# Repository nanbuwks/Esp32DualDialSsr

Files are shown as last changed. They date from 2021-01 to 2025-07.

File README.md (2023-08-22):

# Esp32DualDialSsr

ESP32 board with 2 rotary encoder and 4 ch SSR.

# OVERVIEW


include AC to 12V DC power module and AC (SSR driven 12V). 
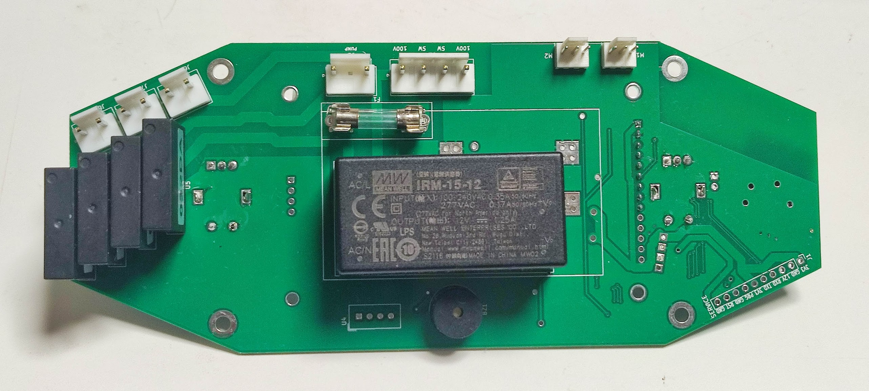
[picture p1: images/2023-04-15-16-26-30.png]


# User Interface
2 rotary encoder and 3.2in TFT LCD module connector



# OUTPUT

2 output but 1ch 12V ON/OFF output for 12V FAN. 
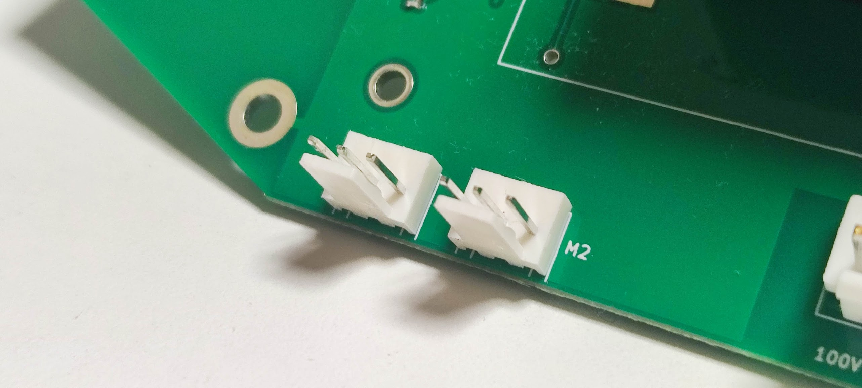
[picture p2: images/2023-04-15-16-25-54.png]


3 + 1 SSR output

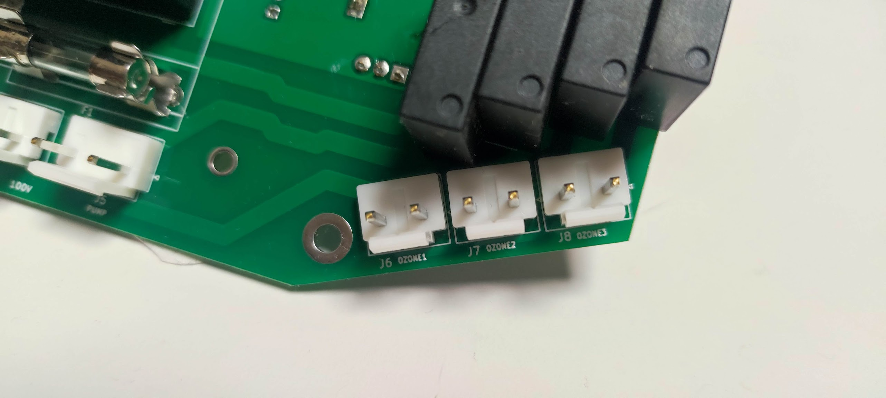
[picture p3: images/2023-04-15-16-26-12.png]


Power IN connector (J2) , fuse (F1) and one of SSR output (J5) 
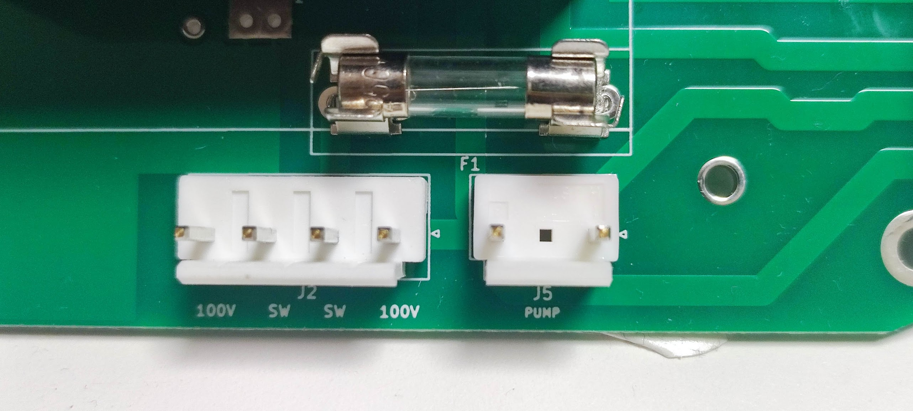
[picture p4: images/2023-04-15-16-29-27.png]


buzzer and temp sensor(optional)
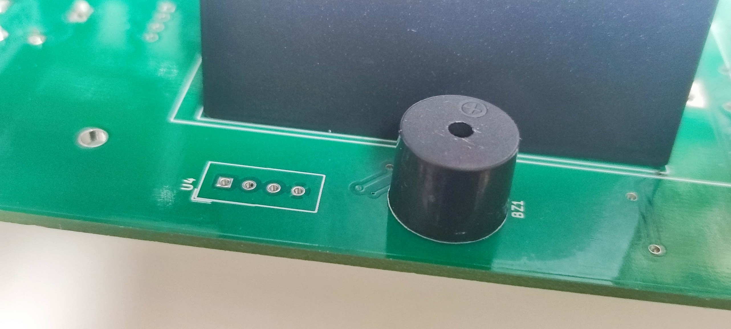
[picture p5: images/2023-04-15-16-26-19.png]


# GPIO settings

## TFT LCD

```
  static constexpr int dma_channel = 1;
  static constexpr int spi_sclk = 18;
  static constexpr int spi_mosi = 23;
  static constexpr int spi_miso = 19;
  static constexpr int spi_dlen = 8;
#define TFT_RST 16
#define TFT_DC 17
#define TFT_CS 5
#define TFT_BACKLIGHT_PIN 4
```

## Rotary Encoder

#define ENCODER1_A_PIN 34
#define ENCODER1_B_PIN 35
#define ENCODER1_SWITCH_PIN 25
#define ENCODER2_A_PIN 12
#define ENCODER2_B_PIN 13
#define ENCODER2_SWITCH_PIN 14

## SSR

```
#define PUMP_PIN 27
SSR control GPIO 26,32,33
```

# OTHER

```
#define FAN_PIN 22
#define BEEP_PIN 2
```

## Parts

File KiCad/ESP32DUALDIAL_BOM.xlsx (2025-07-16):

Comment | Designator | Footprint | JLCPCB Part #（optional）
ESP-WROOM-32-nanbuwks | U2 | ESP-WROOM-32 | C701343 | v
C | C1, C2, C4, C5, C7, C8, C9, C12,C15,C16,C17 | 0.1uF CC0603KRX7R9BB104 | C14663 | v
C | C3, C10, C11 | 10u CL05A106MQ5NUNC | C15525 | v
C | C6 | 20p 0402CG200J500NT | C1554 | v
R | R1,R2, R3, R17, R18, R20, R22 | 10k 0603WAF1002T5E | C25804 | v
R | R5, R6, R7, R8, R11, R12, R13, R14, R15, R16 | 0603WAF6800T5E | C23228 | v
R | R9 | 1k 0603WAF1001T5E | C21190 | v
R | R10 | 100k 0603WAF1003T5E | C25803 | v
DIODE | D1 | MM1W15 | C169504 | v
TBD62783A | U9 | HT62783ARWZ | C2834485 | v
Q_NMOS_GDS | Q1 | 25N06 | C2890396 | v
Fuse | F1 | Fuse | C842712 | v
Conn_01x04_Male | J2 | B04P-NV(LF)(SN) | C160283 | v
Conn_01x03_Male | J5 | B2P3-VH(LF)(SN) | C160745 | v
Conn_01x02_Male | J6, J7, J8 | B02P-NV(LF)(SN) | C160287 | v
Fan_CPU_4pin | M1, M2 | HC-2510-3A | C2982032 | v
C | C13, C14 | 2200p | C389721 | v
R | R23, R24 | 1MΩ | C714630 | V
Buzzer1 | BZ1 | TMB12A03 (https://jlcpcb.com/partdetail/Jiangsu_HuanengElec-TMB12A03/C96222) | C96079
CP | C18 | 47uF | C2943984
CP | C19 | 220uF | C698142
PINSOCKET | U1 | 14PIN | C9900060112
IRM-15-12 | PS1 | 12V Power | C6394169
NNG1D-1/032F-22 2Z | U5,U6,U7,U8 | SSR | C9900059825

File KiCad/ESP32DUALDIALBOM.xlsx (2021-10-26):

Id | SMT/THT | Designator | Package | Quantity | Designation | Side | PIN | Supply
1 | SMT | U2 | ESP-WROOM-32 | 1 | ESP-WROOM-32 | Front | 39 | YES
2 | SMT | C1,C2,C4,C5,C7,C8,C9,C12 | R_0603_1608Metric | 8 | 0.1uF | Front | 16 | YES
3 | SMT | C3,C10,C11 | C_0402_1005Metric | 3 | 10u | Front | 6 | YES
4 | SMT | C6 | C_0402_1005Metric | 1 | 20p | Front | 2 | YES
5 | SMT | R1,R2,R3,R17,R18,R20,R22 | R_0603_1608Metric | 9 | 10k | Front | 18 | YES
6 | SMT | R5,R6,R7,R8,R11,R13,R14,R15,R16,R12 | R_0603_1608Metric | 10 | 680 ohm | Front | 20 | YES
7 | SMT | R9 | R_0603_1608Metric | 1 | 1k | Front | 2 | YES
8 | SMT | R10 | R_0603_1608Metric | 1 | 100k | Front | 2 | YES
9 | SMT | D1 | D_SOD-123F | 1 | D_Schottky | Front | 2 | YES
10 | SMT | U9 | SOIC-18W_7.5x11.6mm_P1.27mm | 1 | TBD62783A | Front | 18 | from Japan 102pcs
11 | SMT | Q1 | TO-252-2 | 1 | Q_NMOS_GDS | Front | 3 | from Japan 90pcs
 |  |  |  |  |  |  | 128
12 | THT | U1 | 2.54mm PINSOCKET | 1 | PINSOCKET 9PIN | Front | 9 | YES
13 | THT | F1 | 20mmFuse_P5x2 | 2 | Fuse Holder | Back | 4 | YES
14 | THT | J2 | JST_NV_B04P-NV_1x04_P5.00mm_Vertical | 1 | 01x04 connector | Back | 4 | from Japan 88pcs
15 | THT | J5 | JST_VH_B3P-VH_1x02_P7.92mm_Vertical | 1 | 01x03 connector | Back | 2 | YES
16 | THT | J6,J7,J8 | JST_NV_B02P-NV_1x02_P5.00mm_Vertical | 3 | 01x02 connector | Back | 2 | YES
17 | THT | M1,M2 | FanPinHeader_1x03_P2.54mm_Vertical | 2 | Fan_CPU_3pin | Back | 6 | YES
18 | THT | U5,U6,U7,U8 | Solid State Relay | 4 | NNC_NNG1D-25mm | Back | 16 | YES
 |  |  |  |  |  |  | 43
 |  | FRONT VIEW |  |  |  |  |  |  | BACK VIEW

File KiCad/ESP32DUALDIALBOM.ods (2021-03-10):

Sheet: ESP32DUALDIAL
Id | Designator | Package | Quantity | Designation | Supplier and ref
17 | U2 | ESP-WROOM-32 | 1 | ESP-WROOM-32
19 | J1 | PinHeader_1x10_P2.54mm_Vertical | 1 | SERVICE
4 | C1,C2,C4,C5,C7,C8,C9,C12 | R_0603_1608Metric | 8 | 0.1uF
5 | C3,C10,C11 | C_0402_1005Metric | 3 | 10u
6 | C6 | C_0402_1005Metric | 1 | 20p | つけてない
10 | R1 | R_0603_1608Metric | 1 | NC
11 | R2 | R_0603_1608Metric | 1 | 10k
12 | R3 | R_0603_1608Metric | 1 | 4.7k
13 | R5,R6,R7,R8 | R_0603_1608Metric | 4 | 330 | 270
14 | R9 | R_0603_1608Metric | 1 | 1k | 2k
15 | R10 | R_0603_1608Metric | 1 | 100k | 753
23 | R4 | R_0603_1608Metric | 1 | NC
27 | D1 | D_SOD-123F | 1 | D_Schottky
9 | Q1 | TO-220-3_Vertical | 1 | Q_NMOS_GDS
8 | PS1 | Converter_ACDC_MeanWell_IRM-20-xx_THT | 1 | IRM-20-12
7 | J3,J4 | PinSocket_1x02_P2.54mm_Vertical | 2 | FAN
24 | U9 | DIP-18_W7.62mm | 1 | TBD62783A
25 | U5,U6,U7,U8 | SSR_SHARP_S108T02 | 4 | S108T02
26 | U3 | QS-1205CME-3A_MINIDC-DC_12-24Vto5V3A_1.8V_2.5V_3.3V_5V_9V_12V | 1 | QS-1205CME-3A_MINIDC-DC_12-24Vto5V3A_1.8V_2.5V_3.3V_5V_9V_12V
28 | F1 | 20mmFuse_P5x2 | 1 | Fuse
29 | J2 | JST_NV_B04P-NV_1x04_P5.00mm_Vertical | 1 | Conn_01x04_Male
30 | J5 | JST_VH_B3P-VH_1x03_P3.96mm_Vertical | 1 | Conn_01x03_Male
31 | J6,J7,J8 | JST_NV_B02P-NV_1x02_P5.00mm_Vertical | 3 | Conn_01x02_Male
1 | U1 | TFT3.2_ILI9341 | 1 | CR2013-MI2120
2 | BZ1 | Buzzer_12x9.5RM7.6 | 1 | Buzzer
16 | SW1,SW2 | RotaryEncoder_Alps_EC11E-Switch_Vertical_H20mm | 2 | Rotary_Encoder_Switch
 |  | ADJ 23k-3.3V
 | 緑系列 | 9.3 | 1.8V
 |  | 15.8 | 2.5V
 |  | 23.3 | 3.3V
 |  | 39 | 5V
 |  | 72 | 9V
 |  | 102 | 12V
 | 赤系列
 |  | 23 | 3.3V
 |  | 39
 |  | 76
 |  | 102
 |  | JoulWatt Tech JW5068A
 | Mini560

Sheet: Sheet2
 | 今ある数
B04P-NV | 66
B02P-NV | 64
B3PS-VH | 1450
MOSFET | 250
ESP32 | 250
SSR | 350

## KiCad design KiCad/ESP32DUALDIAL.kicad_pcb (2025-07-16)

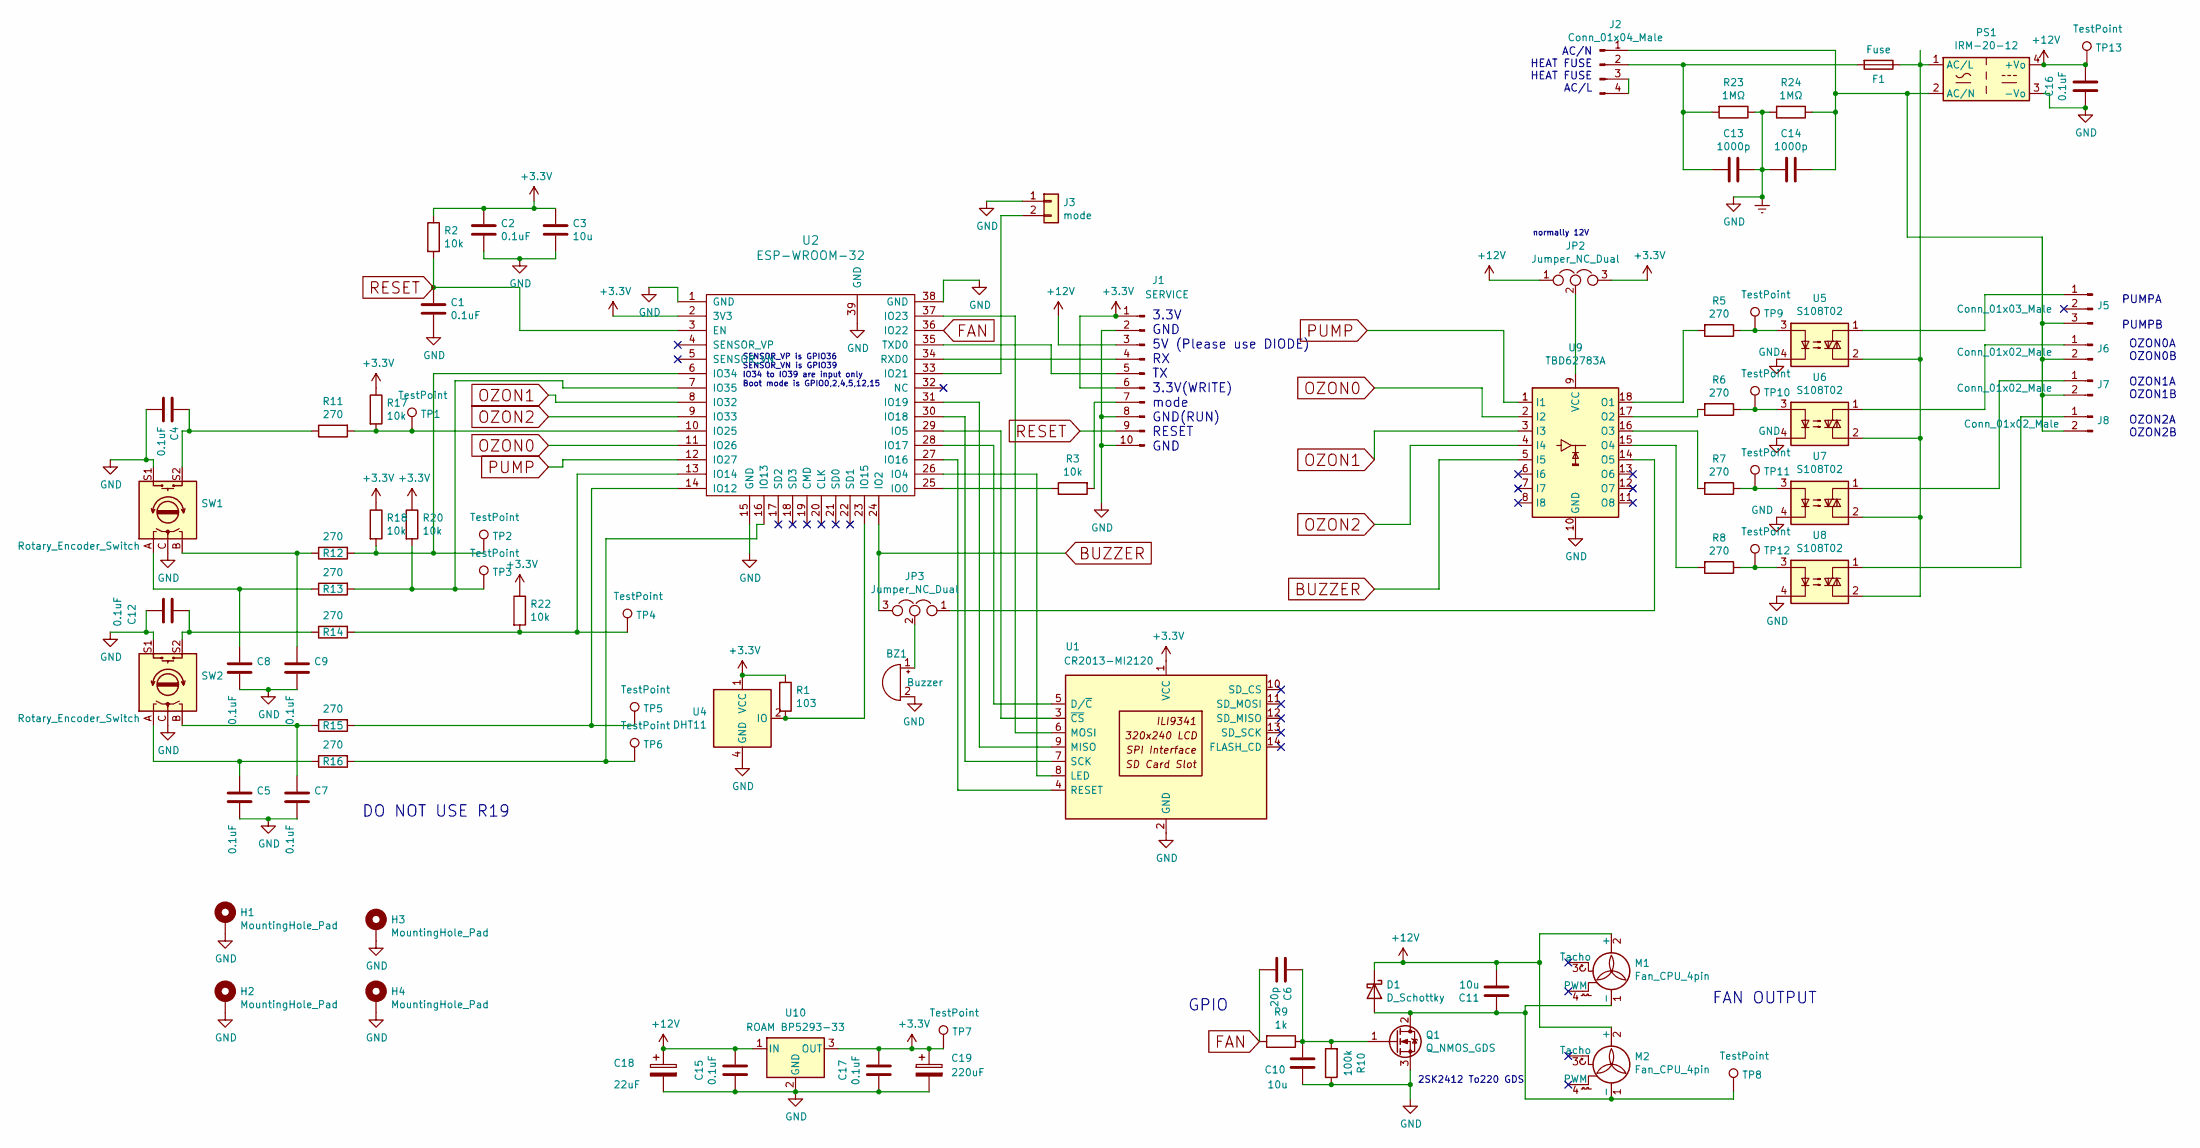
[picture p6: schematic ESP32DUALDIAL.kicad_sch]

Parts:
BZ1: Buzzer; Buzzer_7.6_5.0
C1, C2, C4, C5, C7, C8, C9, C12: 0.1uF; R_0603_1608Metric
C3, C10, C11: 10u; C_0402_1005Metric
C6: 20p; C_0402_1005Metric
C13, C14: 1000p; C_Disc_D10.5mm_W5.0mm_P10.00mm
C15, C16, C17: 0.1uF; C_0603_1608Metric
C18: 22uF; CP_Radial_D6.3mm_P2.50mm
C19: 220uF; CP_Radial_D5.0mm_P2.00mm
D1: D_Schottky; D_SOD-123F
F1: Fuse; 20mmFuse_P5x2
H1, H2, H3, H4: MountingHole_Pad; MountingHole_3.2mm_M3_Pad
J1: SERVICE; PinHeader_1x10_P2.54mm_Vertical
J2: Conn_01x04_Male; JST_NV_B04P-NV_1x04_P5.00mm_Vertical
J3: mode; PinHeader_2x01_P2.54mm_Vertical
J5: Conn_01x03_Male; JST_VH_B3P-VH_1x03_P3.96mm_Vertical
J6, J7, J8: Conn_01x02_Male; JST_NV_B02P-NV_1x02_P5.00mm_Vertical
JP2, JP3: Jumper_NC_Dual; SolderJumper-3_P1.3mm_Bridged12_RoundedPad1.0x1.5mm_NumberL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
M1, M2: Fan_CPU_4pin; FanPinHeader_1x03_P2.54mm_Vertical
PS1: IRM-20-12; Converter_ACDC_MeanWell_IRM-20-xx_THT
Q1: Q_NMOS_GDS; TO-252-2
R1: 103; R_0603_1608Metric
R2, R3, R17, R18, R20, R22: 10k; R_0603_1608Metric
R5, R6, R7, R8, R11, R12, R13, R14, R15, R16: 270; R_0603_1608Metric
R9: 1k; R_0603_1608Metric
R10: 100k; R_0603_1608Metric
R23, R24: 1MΩ; R_Axial_DIN0207_L6.3mm_D2.5mm_P10.16mm_Horizontal
SW1, SW2: Rotary_Encoder_Switch; RotaryEncoder_Alps_EC11E-Switch_Vertical_H20mm
TP1, TP2, TP3, TP4, TP5, TP6, TP8, TP9, TP10, TP11, TP12: TestPoint; TestPoint_Pad_D2.0mm
TP7, TP13: TestPoint; TestPoint_Pad_D3.0mm
U1: CR2013-MI2120; TFT3.2_ILI9341
U2: ESP-WROOM-32
U4: DHT11; Aosong_DHT11_5.5x12.0_P2.54mm
U5, U6, U7, U8: S108T02; SSR_SHARP_S108T02_NNC_NNG1D-25mm
U9: TBD62783A; SOIC-18W_7.5x11.6mm_P1.27mm
U10: ROAM BP5293-33; Converter_DCDC_RECOM_R-78E-0.5_THT

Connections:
+3V3: C2.1, C3.1, C17.1, C19.1, J1.1, J1.6, JP2.3, R1.1, R2.1, R17.1, R18.1, R20.1, R22.1, TP7.1, U1.1 (VCC), U2.2 (3V3), U4.1 (VCC), U10.3 (OUT)
+12V: C11.2, C15.1, C16.1, C18.1, D1.1 (K), J1.3, JP2.1, M1.2 (+), M2.2 (+), PS1.4 (+Vo), TP13.1, U10.1 (IN)
BUZZER: JP3.3, U2.24 (IO2), U9.5 (I5)
Earth: BZ1.2 (+), C1.2, C2.2, C3.2, C4.2, C5.2, C7.2, C8.2, C9.2, C10.1, C12.2, C13.1, C14.2, C15.2, C16.2, C17.2, C18.2, C19.2, H1.1, H2.1, H3.1, H4.1, J1.2, J1.8, J1.10, J3.1, PS1.3 (-Vo), Q1.3 (S), R10.1, R23.1, R24.2, SW1.C, SW1.S1, SW2.C, SW2.S1, U1.2 (GND), U2.1 (GND), U2.15 (GND), U2.38 (GND), U2.39 (GND), U4.4 (GND), U5.4, U6.4, U7.4, U8.4, U9.10 (GND), U10.2 (GND)
FAN: C6.2, R9.2, U2.36 (IO22)
unnamed: BZ1.1 (-), JP3.2
unnamed: C4.1, R11.1, SW1.S2
unnamed: C5.1, R16.1, SW2.A
unnamed: C7.1, R15.1, SW2.B
unnamed: C8.1, R13.1, SW1.A
unnamed: C9.1, R12.1, SW1.B
unnamed: C12.1, R14.1, SW2.S2
unnamed: C11.1, D1.2 (A), M1.1 (-), M2.1 (-), Q1.2 (D), TP8.1
unnamed: J1.4, U2.34 (RXD0)
unnamed: J1.5, U2.35 (TXD0)
unnamed: J1.7, R3.2
unnamed: C14.1, J2.1, J5.3, J6.2, J7.2, J8.2, PS1.2 (AC/N), R24.1
unnamed: C13.2, F1.2, J2.2, R23.2
unnamed: J2.3, J2.4
unnamed: J3.2, U2.33 (IO21)
unnamed: J5.1, U5.1
unnamed: J6.1, U6.1
unnamed: J7.1, U7.1
unnamed: J8.1, U8.1
unnamed: F1.1, PS1.1 (AC/L), U5.2, U6.2, U7.2, U8.2
unnamed: C6.1, C10.2, Q1.1 (G), R9.1, R10.2
unnamed: R5.1, TP9.1, U5.3
unnamed: R6.1, TP10.1, U6.3
unnamed: R7.1, TP11.1, U7.3
unnamed: R8.1, TP12.1, U8.3
unnamed: U1.5 (D/~C), U2.28 (IO17)
unnamed: U1.8 (LED), U2.26 (IO4)
unnamed: U1.9 (MISO), U2.31 (IO19)
unnamed: U1.6 (MOSI), U2.37 (IO23)
unnamed: U1.4 (RESET), U2.27 (IO16)
unnamed: U1.7 (SCK), U2.30 (IO18)
unnamed: U1.3 (~CS), U2.29 (IO5)
unnamed: R3.1, U2.25 (IO0)
unnamed: R15.2, TP5.1, U2.14 (IO12)
unnamed: R16.2, TP6.1, U2.16 (IO13)
unnamed: R14.2, R22.2, TP4.1, U2.13 (IO14)
unnamed: R1.2, U2.23 (IO15), U4.2 (IO)
unnamed: R11.2, R17.2, TP1.1, U2.10 (IO25)
unnamed: R12.2, R18.2, TP2.1, U2.6 (IO34)
unnamed: R13.2, R20.2, TP3.1, U2.7 (IO35)
unnamed: R5.2, U9.18 (O1)
unnamed: R6.2, U9.17 (O2)
unnamed: R7.2, U9.16 (O3)
unnamed: R8.2, U9.15 (O4)
unnamed: JP3.1, U9.14 (O5)
unnamed: JP2.2, U9.9 (VCC)
OZON0: U2.11 (IO26), U9.2 (I2)
OZON1: U2.8 (IO32), U9.3 (I3)
OZON2: U2.9 (IO33), U9.4 (I4)
PUMP: U2.12 (IO27), U9.1 (I1)
RESET: C1.1, J1.9, R2.2, U2.3 (EN)

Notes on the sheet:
normally 12V
FAN OUTPUT
3.3V GND 5V (Please use DIODE) RX TX 3.3V(WRITE) mode GND(RUN) RESET GND
OZON0A OZON0B OZON1A OZON1B OZON2A OZON2B
GPIO
AC/N HEAT FUSE HEAT FUSE AC/L
PUMPA PUMPB
2SK2412 To220 GDS
DO NOT USE R19
SENSOR_VP is GPIO36 SENSOR_VN is GPIO39 IO34 to IO39 are input only Boot mode is GPIO0,2,4,5,12,15

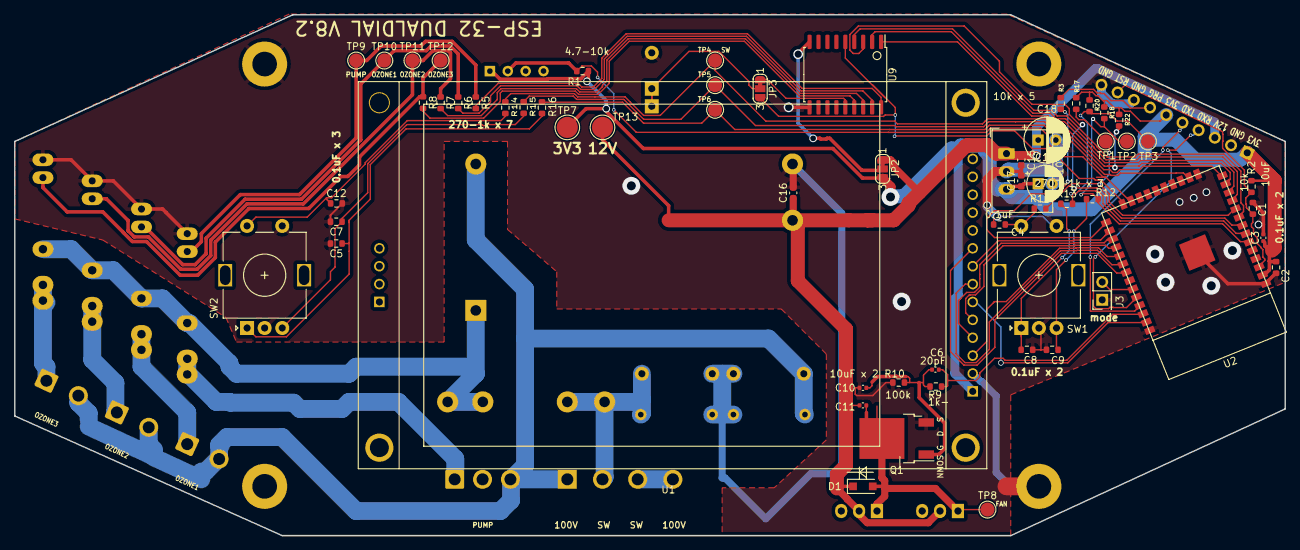
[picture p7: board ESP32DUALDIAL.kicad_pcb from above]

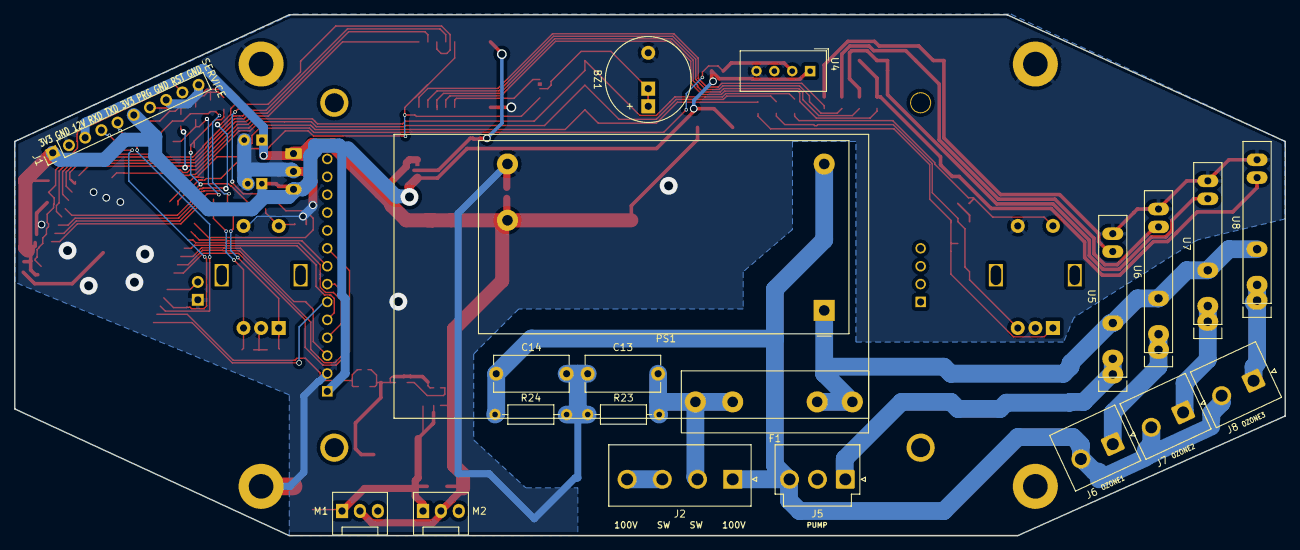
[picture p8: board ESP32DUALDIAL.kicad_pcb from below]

Board: 2 copper layers, 180.5 x 74.0 mm, 84 parts (20 on the bottom side), 56 nets.

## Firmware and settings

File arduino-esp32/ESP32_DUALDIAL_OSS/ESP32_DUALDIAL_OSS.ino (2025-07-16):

#include <LovyanGFX.hpp>

/*
#include <LovyanGFX.hpp>  

*/
//#include <SPIFFS.h>
//#include <FS.h>
#include <EEPROM.h>
#define VERSION "Ver1.43"
#define MODEXDEFAULT 0
// 1 ... 空間除菌有効
#include "commercial.h"
struct LGFX_Config
{
  static constexpr spi_host_device_t spi_host = VSPI_HOST;
  static constexpr int dma_channel = 1;
  static constexpr int spi_sclk = 18;
  static constexpr int spi_mosi = 23;
  static constexpr int spi_miso = 19;
  static constexpr int spi_dlen = 8;
};
static lgfx::LGFX_SPI<LGFX_Config> tft;
static lgfx::Panel_ILI9341 panel;
static LGFX_Sprite sprite(&tft);
#include <RotaryEncoder.h>


// #define DEBUG
#define OZONELIFELIMIT 600 * 3600 // 600時間
#define BEEP


#define TFT_RST 16
#define TFT_DC 17
#define TFT_CS 5
#define PUMP_PIN 27

#define FAN_PIN 22
#define BEEP_PIN 2

// ozone チューブコントロールGPIO番号
int  OZONE_PIN[3] = { 26, 32, 33 };
// ozone チューブ利用優先順位 (利用時間短いものから優先使用)
int OZONEorder[3] = {0, 1, 2};


//  Switch DEBUG
/*
  #define ENCODER1_A_PIN 25   // ロータリーエンコーダーをスイッチ代わり
  #define ENCODER1_B_PIN 35
  #define ENCODER1_SWITCH_PIN 34
  #define ENCODER2_A_PIN 12
  #define ENCODER2_B_PIN 13
  #define ENCODER2_SWITCH_PIN 14
*/
// Not Switch DEBUG (normal)

#define ENCODER1_A_PIN 34
#define ENCODER1_B_PIN 35
#define ENCODER1_SWITCH_PIN 25
#define ENCODER2_A_PIN 12
#define ENCODER2_B_PIN 13
#define ENCODER2_SWITCH_PIN 14


#define TFT_BACKLIGHT_PIN 4
#define FRAMERATEDELAY 60

#define WAITTIMEMAX 82
#define TIMEMAX 64

#define OZONEMAX 5
#define Ozone_WARN_LIMIT 3

const char* recordfile = "/timerecord.txt";
RTC_DATA_ATTR int bootCount = 0;


RotaryEncoder encoder1(ENCODER1_A_PIN, ENCODER1_B_PIN);
RotaryEncoder encoder2(ENCODER2_A_PIN, ENCODER2_B_PIN);



LABEL maintenanceLabels1[6] = { md120, md121, md122, md123 , md124 , md130 };
LABEL maintenanceLabels2[8] = { md210, md211, md212, md213, md214, md215, m216, m217 };
// LABEL setLabels[2]={ setCONNECT,setRETURN};
// LABEL scanLabels[4]={ scannode1,scannode2,scannode3,scannode4};


int ozonePercent[OZONEMAX + 1] = { 7, 15, 20, 50, 70, 100 };
int timeSeconds[WAITTIMEMAX + 1] = {
#ifdef DEBUG
  1,    2,  3, 4,  5,  6,  7,  8,  9,  10,  11,  12,  13,  14,  15,  510,  540,  570,  600,  630,
#else
  60,    90,  120, 150,  180,  210,  240,  270,  300,  330,  360,  390,  420,  450,  480,  510,  540,  570,  600,  630,
#endif
  660,  690,  720, 750,  780,  810,  840,  870,  900,  930,  960,  990, 1020, 1050, 1080, 1110, 1140, 1170, 1200, 1230,
  1260, 1290, 1320, 1350, 1380, 1410, 1440, 1470, 1500, 1530, 1560, 1590, 1620, 1650, 1680, 1710, 1740, 1770, 1800, 2700,
  3600, 5400, 7200, 9000, 10800, 12600, 14400, 16200, 18000, 19800, 21600, 23400, 25200, 27000, 28800, 30600, 32400, 34200, 36000, 37800,
  39600, 41400, 43200
};
// sprite design
  int16_t spriteoffsetx=40, spriteoffsety=100;
  int16_t spritesizex=240, spritesizey=64;
  
// EEPROM paramater
int maintenance_Count = 1;
int oneshot_Ozonelevel = 2;
int oneshot_endtime = 1;
int program_Ozonelevel = 1;
int program_starttime = 61;
int program_endtime = 61;
int log_pump = 0;
int log_ozone = 0;
int log_ozone10; // log_ozoneの10倍
int log_fan = 0;
int log_oncount = 0;
int log_OZONE10[3] = {0, 0, 0}; // 0.1秒単位の稼働時間
int mode_X = MODEXDEFAULT;

// run time using
String mode = "set"; // set,run,resetting
String motionPUMP = "OFF"; // ON/OFF
String motionFAN = "OFF"; // ON/OFF
String motionOZONE = "OFF"; // ON/OFF

int runRemain;      // remain countdown second
int settingRemain;   // setting second
int autoExitCounter; // countdown second
int timercounter = 0;
int Ozonelevel = 0; // 0 to 6 この変数を変更するとオゾン発生に即反映される
int Ozonedisplay = 3;  // 設定中の値 現在は Ozonelevel = Ozonedisplay

static int encoder1Pushed = 0; // you must turn 0 after button check
static int encoder1Pushing = 0;
static int encoder2Pushed = 0; // you must turn 0 after button check
static int encoder2Pushing = 0;

// colors
int OzoneBgColor = TFT_BLACK;
int OzoneFgColor = TFT_BLACK;
int OzonePnColor = TFT_LIGHTGRAY;
int OzoneTitleColor = TFT_BLUE;


hw_timer_t * timer = NULL;

void IRAM_ATTR onTimer() {  // each 20msec
  //  encoder2.tick(); // just call tick() to check the state.
  //  encoder1.tick(); // just call tick() to check the state.
  timercounter++;
  if ( motionOZONE == "ON" ) {

    if ( 2 <  Ozonelevel ) {
      runFAN();
    } else {
      stopFAN();
    }
    /*
      if ( ozonePercent[Ozonelevel] == timercounter % 100 )  // 100 means 20msec * 100 = 2 sec.
      digitalWrite(OZONE_PIN[0], LOW);
      if ( 0                        == timercounter % 100 )
      digitalWrite(OZONE_PIN[0], HIGH);
      if ( ozonePercent[Ozonelevel] == ( timercounter + 33 ) % 100 )
      digitalWrite(OZONE_PIN[1], LOW);
      if ( 0                        == ( timercounter + 33 ) % 100 )
      digitalWrite(OZONE_PIN[1], HIGH);
      if ( ozonePercent[Ozonelevel] == ( timercounter + 66 ) % 100 )
      digitalWrite(OZONE_PIN[2], LOW);
      if ( 0                        == ( timercounter + 66 ) % 100 )
      digitalWrite(OZONE_PIN[2], HIGH);
    */
    if ( 1 == mode_X ) {  // 空間除菌有効の場合
      if ( 0 == Ozonelevel ) {
        digitalWrite(OZONE_PIN[OZONEorder[1]], LOW);
        digitalWrite(OZONE_PIN[OZONEorder[2]], LOW);
        if (  0 == timercounter % 100 ) // 100 means 20msec * 100 = 2 sec.
          digitalWrite(OZONE_PIN[OZONEorder[0]], HIGH);
        if ( 33 == timercounter % 100 ) // 33 means duty 33%
          digitalWrite(OZONE_PIN[OZONEorder[0]], LOW);
        if ( 0 == timercounter % 500  ) // each 10 sec.
          log_OZONE10[OZONEorder[0]] +=  33;  // 3.3秒を追加記録
      }
      if ( 1 == Ozonelevel ) {
        digitalWrite(OZONE_PIN[OZONEorder[1]], LOW);
        digitalWrite(OZONE_PIN[OZONEorder[2]], LOW);
        if (  0 == timercounter % 100 ) // 100 means 20msec * 100 = 2 sec.
          digitalWrite(OZONE_PIN[OZONEorder[0]], HIGH);
        if ( 66 == timercounter % 100 ) // 33 means duty 33%
          digitalWrite(OZONE_PIN[OZONEorder[0]], LOW);
        if ( 0 == timercounter % 500  ) // each 10 sec.
          log_OZONE10[OZONEorder[0]] +=  66;  // 6.6秒を追加記録
      }
      if ( 2 == Ozonelevel ) {
        digitalWrite(OZONE_PIN[OZONEorder[1]], LOW);
        digitalWrite(OZONE_PIN[OZONEorder[2]], LOW);
        digitalWrite(OZONE_PIN[OZONEorder[0]], HIGH);
        if ( 0 == timercounter % 500  ) // each 10 sec.
          log_OZONE10[OZONEorder[0]] +=  100;  // 10秒を追加記録
      }
      if ( 3 == Ozonelevel ) {
        digitalWrite(OZONE_PIN[OZONEorder[1]], LOW);
        digitalWrite(OZONE_PIN[OZONEorder[2]], LOW);
        digitalWrite(OZONE_PIN[OZONEorder[0]], HIGH);
        if ( 0 == timercounter % 500  ) // each 10 sec.
          log_OZONE10[OZONEorder[0]] +=  100;  // 10秒を追加記録
      }
      if ( 4 == Ozonelevel ) {
        digitalWrite(OZONE_PIN[OZONEorder[1]], HIGH);
        digitalWrite(OZONE_PIN[OZONEorder[0]], HIGH);
        digitalWrite(OZONE_PIN[OZONEorder[2]], LOW);
        if ( 0 == timercounter % 500  ){ // each 10 sec.
          log_OZONE10[OZONEorder[0]] +=  100;  // 10秒を追加記録
          log_OZONE10[OZONEorder[1]] +=  100;  // 10秒を追加記録
        } 
      }
      if ( 5 == Ozonelevel ) {
        digitalWrite(OZONE_PIN[OZONEorder[1]], HIGH);
        digitalWrite(OZONE_PIN[OZONEorder[0]], HIGH);
        digitalWrite(OZONE_PIN[OZONEorder[2]], HIGH);
        if ( 0 == timercounter % 500  ){ // each 10 sec.
          log_OZONE10[OZONEorder[0]] +=  100;  // 10秒を追加記録
          log_OZONE10[OZONEorder[1]] +=  100;  // 10秒を追加記録
          log_OZONE10[OZONEorder[2]] +=  100;  // 10秒を追加記録
        }
      }
    } else {
      if ( 0 == Ozonelevel ) {
        if (  0 == timercounter % 100 ) // 100 means 20msec * 100 = 2 sec.
          digitalWrite(OZONE_PIN[OZONEorder[0]], HIGH);
        if ( 17 == timercounter % 100 ) // 17 means duty 17%
          digitalWrite(OZONE_PIN[OZONEorder[0]], LOW);
        if ( 0 == timercounter % 500  ) // each 10 sec.
          log_OZONE10[OZONEorder[0]] +=  17;  // 1.7秒を追加記録
      }
      if ( 1 == Ozonelevel ) {
        if (  0 == timercounter % 100 ) // 100 means 20msec * 100 = 2 sec.
          digitalWrite(OZONE_PIN[0], HIGH);
        if ( 33 == timercounter % 100 ) // 33 means duty 33%
          digitalWrite(OZONE_PIN[0], LOW);
        if ( 0 == timercounter % 500  ) // each 10 sec.
          log_OZONE10[0] +=  33;  // 3.3秒を追加記録
      }
      if ( 2 == Ozonelevel ) {
        if (  0 == timercounter % 100 ) // 100 means 20msec * 100 = 2 sec.
          digitalWrite(OZONE_PIN[0], HIGH);
        if ( 48 == timercounter % 100 ) // 48 means duty 48%
          digitalWrite(OZONE_PIN[0], LOW);
        if ( 0 == timercounter % 500  ) // each 10 sec.
          log_OZONE10[0] +=  48;  // 4.8秒を追加記録
      }
      if ( 3 == Ozonelevel ) {
        if (  0 == timercounter % 100 ) // 100 means 20msec * 100 = 2 sec.
          digitalWrite(OZONE_PIN[0], HIGH);
        if ( 66 == timercounter % 100 ) // 66 means duty 66%
          digitalWrite(OZONE_PIN[0], LOW);
        if ( 0 == timercounter % 500  ) // each 10 sec.
          log_OZONE10[0] +=  66;  // 6.6秒を追加記録
      }
      if ( 4 == Ozonelevel ) {
        if (  0 == timercounter % 100 ) // 100 means 20msec * 100 = 2 sec.
          digitalWrite(OZONE_PIN[0], HIGH);
        if ( 83 == timercounter % 100 ) // 83 means duty 83%
          digitalWrite(OZONE_PIN[0], LOW);
        if ( 0 == timercounter % 500  ) // each 10 sec.
          log_OZONE10[0] +=  83;  // 8.3秒を追加記録
      }
      if ( 5 == Ozonelevel ) {
        digitalWrite(OZONE_PIN[0], HIGH);
        if ( 0 == timercounter % 500  ) // each 10 sec.
          log_OZONE10[0] +=  100;  // 10秒を追加記録
      }      
    }

    if ( 0 == timercounter % 500  ) // each 10 sec.
      log_ozone10 = log_ozone10 + ozonePercent[Ozonelevel];
  }
  if ( 0 == timercounter % 5 )
    countdown();
}

void IRAM_ATTR ISR() {
  encoder2.tick(); // just call tick() to check the state.
  encoder1.tick(); // just call tick() to check the state.

}



void IRAM_ATTR RELEASE1() {
  static unsigned long nowtime;
  static unsigned long oldtime = 0;
  nowtime = millis();
  if ( 150 < ( nowtime - oldtime )) {
    /*

        Serial.print("released!!!!!!!!!!");
        Serial.print(oldtime);
        Serial.print("  ");
        Serial.println(nowtime);
        Serial.print("1release");
    */
    encoder1Pushed = 1;

    encoder1Pushing = 0;
  }
  /*
      Core  1 panic'ed (Interrupt wdt timeout on CPU1) 対策でコメントアウト

    Serial.print(nowtime);
    Serial.print("-------------------------------------------------------------------------------------------------------------------------------------------------------------------------- ");
    Serial.print(encoder1Pushed);
    Serial.print(" ");
    Serial.print(encoder1Pushing);
    Serial.print(" ");
    Serial.print(encoder2Pushed);
    Serial.print(" ");
    Serial.print(encoder2Pushing);
    Serial.println(" ");
  */
  oldtime = nowtime;
}
void IRAM_ATTR RELEASE2() {
  static unsigned long nowtime;
  static unsigned long oldtime = 0;
  nowtime = millis();
  if ( 150 < ( nowtime - oldtime )) {
    encoder2Pushed = 1;
    encoder2Pushing = 0;
  }
  /*
      Core  1 panic'ed (Interrupt wdt timeout on CPU1) 対策でコメントアウト
       Serial.print(" ");
    Serial.print(encoder1Pushed);
    Serial.print(" ");
    Serial.print(encoder1Pushing);
    Serial.print(" ");
    Serial.print(encoder2Pushed);
    Serial.print(" ");
    Serial.print(encoder2Pushing);
    Serial.println(" ");
  */
  oldtime = nowtime;
}

void countdown() { // Timer割り込みから呼び出される
  // each 100 msec.
  static int countdowncounter = 0;
  countdowncounter++;
  //Serial.print(countdowncounter);

  if ( mode == "notify" ) {
    if ( 0 == countdowncounter % 10 )
    {
      // Serial.printf("runRemain:%d", runRemain);
      runRemain--;
      // Serial.printf("runRemain:%d", runRemain);
      if ( 0 > runRemain )
      {
        runRemain = 0;
      }
    }
  }
  if ( mode == "run" ) { // timeStateだけ0.5秒間隔で点滅
    if ( 0 == countdowncounter % 10 )
    {
      timeState.fgcolor = TFT_GREEN;
    }
    if ( 5 == countdowncounter % 10 )
    {
      ozoneChangeColor(encoder2.getPosition());
    }

    if ( 0 == countdowncounter % 10 )
    {
      runRemain--;
      // Serial.printf("runRemain:%d", runRemain);
      if ( 0 > runRemain )
      {
        runRemain = 0;
      }
      // 表示用ラベルを更新
      char buf[20];
      int seconds = runRemain;
      if ( seconds >= 3600 ) {
        sprintf(buf, "%2d", seconds / 3600);
        timeHour.text = String(buf);
        sprintf(buf, "%02d", (seconds / 60) % 60);
        timeMinute.text = String(buf);
        sprintf(buf, "%02d", seconds % 60);
        timeSecond.text = String(buf);
      } else if ( seconds < 3600 && seconds >= 60 ) {
        sprintf(buf, "  ");
        timeHour.text = String(buf);
        sprintf(buf, "%2d", (seconds / 60) % 60);
        timeMinute.text = String(buf);
        sprintf(buf, "%02d", seconds % 60);
        timeSecond.text = String(buf);
      } else if ( seconds < 60 ) {
        sprintf(buf, "  ");
        timeHour.text = String(buf);
        sprintf(buf, "  ");
        timeMinute.text = String(buf);
        sprintf(buf, "%2d", seconds % 60);
        timeSecond.text = String(buf);
      }
    }
  }

  if ( mode == "programmode1" || mode == "programmode2" ) {
    //     Serial.println(countdowncounter);


    if ( 0 == countdowncounter % 10 )// timeStateだけ0.5秒間隔で点滅
    {
      timeState.fgcolor = TFT_GREEN;
    }
    if ( 5 == countdowncounter % 10 )
    {
      ozoneChangeColor(encoder2.getPosition());
    }



    if ( 0 == countdowncounter % 10 )
    {
      runRemain--;
      if ( 0 > runRemain )
        runRemain = 0;
      // 表示用ラベルを更新
      char buf[20];
      int seconds = runRemain;
      if ( seconds >= 3600 ) {
        sprintf(buf, "%2d", seconds / 3600);
        timeHour.text = String(buf);
        sprintf(buf, "%02d", (seconds / 60) % 60);
        timeMinute.text = String(buf);
        sprintf(buf, "%02d", seconds % 60);
        timeSecond.text = String(buf);
      } else if ( seconds < 3600 && seconds >= 60 ) {
        sprintf(buf, "  ");
        timeHour.text = String(buf);
        sprintf(buf, "%2d", (seconds / 60) % 60);
        timeMinute.text = String(buf);
        sprintf(buf, "%02d", seconds % 60);
        timeSecond.text = String(buf);
      } else if ( seconds < 60 ) {
        sprintf(buf, "  ");
        timeHour.text = String(buf);
        sprintf(buf, "  ");
        timeMinute.text = String(buf);
        sprintf(buf, "%2d", seconds % 60);
        timeSecond.text = String(buf);
      }
    }
  }

  if ( mode == "resetting" ) {


    if ( 0 == countdowncounter % 5 )
    {
      timeState.fgcolor = TFT_GREEN;
      timeHour.fgcolor = TFT_GREEN;
      timeMinute.fgcolor = TFT_GREEN;
      timeSecond.fgcolor = TFT_GREEN;
      timeZikan.fgcolor = TFT_GREEN;
      timeFan.fgcolor = TFT_GREEN;
      timeByou.fgcolor = TFT_GREEN;
    }
    if ( 2 == countdowncounter % 5 )
    {
      ozoneChangeColor(encoder2.getPosition());
    }
    if ( 0 == countdowncounter % 10 )
    {
      runRemain--;
      if ( 0 > runRemain )
        runRemain = 0;
      autoExitCounter--;
      if ( 0 > autoExitCounter )
        autoExitCounter = 0;
    }
  }
  if ( mode == "programmode2resetting" ) {
    if ( 0 == countdowncounter % 5 )
    {
      timeState.fgcolor = TFT_GREEN;
      timeHour.fgcolor = TFT_GREEN;
      timeMinute.fgcolor = TFT_GREEN;
      timeSecond.fgcolor = TFT_GREEN;
      timeZikan.fgcolor = TFT_GREEN;
      timeFan.fgcolor = TFT_GREEN;
      timeByou.fgcolor = TFT_GREEN;

    }
    if ( 2 == countdowncounter % 5 )
    {
      ozoneChangeColor(encoder2.getPosition());
    }
    if ( 0 == countdowncounter % 10 )
    {
      runRemain--;
      if ( 0 > runRemain )
        runRemain = 0;
      autoExitCounter--;
      if ( 0 > autoExitCounter )
        autoExitCounter = 0;
    }

  }
  if ( mode == "programmode1resetting" ) {

    if ( 0 == countdowncounter % 5 )
    {
      timeState.fgcolor = TFT_GREEN;
      timeHour.fgcolor = TFT_GREEN;
      timeMinute.fgcolor = TFT_GREEN;
      timeSecond.fgcolor = TFT_GREEN;
      timeZikan.fgcolor = TFT_GREEN;
      timeFan.fgcolor = TFT_GREEN;
      timeByou.fgcolor = TFT_GREEN;
    }
    if ( 2 == countdowncounter % 5 )
    {
      ozoneChangeColor(encoder2.getPosition());
    }
    if ( 0 == countdowncounter % 10 )
    {
      runRemain--;
      if ( 0 > runRemain )
        runRemain = 0;
      autoExitCounter--;
      if ( 0 > autoExitCounter )
        autoExitCounter = 0;
    }
  }
  if ( 0 == countdowncounter % 10 )
  {
    if ( motionPUMP == "ON" )
      log_pump++;
    if ( motionFAN == "ON" )
      log_fan++;
  }
}
int maintenanceSelect1() {
  static int timeminutes = 30;
  encoder1.setPosition(0);
  int startpos = encoder1.getPosition();
  int pos1 = 100;
  int newPos1 = encoder1.getPosition();
  int exitflag = 0;
  int selected;
  //  while ( 0 == exitflag )
  while (1)
  {
    newPos1 = encoder1.getPosition();
    Serial.println(newPos1);

    if (pos1 != newPos1) {
      Serial.print("pos1=");
      Serial.print(newPos1);
      Serial.println();
      pos1 = newPos1;
      selected = (( pos1 % 6) + 6 ) % 6; // negative modulo
      for ( int i = 0; i < 6; i++ ) {
        if ( i == selected) {
          selectLabelText(maintenanceLabels1[i]);
        } else {
          labelText(maintenanceLabels1[i]);
        }
      }
    }

    if ( 1 == encoder1Pushed ) {
      encoder1Pushed = 0;
      switch (selected) {
        case 5:
          // modeX
          Serial.println("modeX change");
          if (  maintenanceLabels1[selected].text == "OFF" ) {
            maintenanceLabels1[selected].text = "ON";
            selectLabelText(maintenanceLabels1[selected]);
            mode_X = 1;
            eeprom_write();
            if ( 0 != eeprom_verify())
              Serial.printf("error EEPROM\n");
          } else {
            maintenanceLabels1[selected].text = "OFF";
            selectLabelText(maintenanceLabels1[selected]);
            digitalWrite(PUMP_PIN, LOW);
            mode_X = 0;
            eeprom_write();
            if ( 0 != eeprom_verify())
              Serial.printf("error EEPROM\n");

          }
          break;
        case 0:
          // pump
          if (  maintenanceLabels1[selected].text == "OFF" ) {
            maintenanceLabels1[selected].text = "ON";
            selectLabelText(maintenanceLabels1[selected]);
            digitalWrite(PUMP_PIN, HIGH);
          } else {
            maintenanceLabels1[selected].text = "OFF";
            selectLabelText(maintenanceLabels1[selected]);
            digitalWrite(PUMP_PIN, LOW);
          }
          break;
        case 1:
          // ozone0
          if (  maintenanceLabels1[selected].text == "OFF" ) {
            maintenanceLabels1[selected].text = "ON";
            selectLabelText(maintenanceLabels1[selected]);
            digitalWrite(OZONE_PIN[0], HIGH);
          } else {
            maintenanceLabels1[selected].text = "OFF";
            selectLabelText(maintenanceLabels1[selected]);
            digitalWrite(OZONE_PIN[0], LOW);
          }
          break;
        case 2:
          // ozone1
          if (  maintenanceLabels1[selected].text == "OFF" ) {
            maintenanceLabels1[selected].text = "ON";
            selectLabelText(maintenanceLabels1[selected]);
            digitalWrite(OZONE_PIN[1], HIGH);
          } else {
            maintenanceLabels1[selected].text = "OFF";
            selectLabelText(maintenanceLabels1[selected]);
            digitalWrite(OZONE_PIN[1], LOW);
          }
          break;

        case 3:
          // ozone2
          if (  maintenanceLabels1[selected].text == "OFF" ) {
            maintenanceLabels1[selected].text = "ON";
            selectLabelText(maintenanceLabels1[selected]);
            digitalWrite(OZONE_PIN[2], HIGH);
          } else {
            maintenanceLabels1[selected].text = "OFF";
            selectLabelText(maintenanceLabels1[selected]);
            digitalWrite(OZONE_PIN[2], LOW);
          }
          break;

        case 4:
          // ozone
          log_ozone10 = 0;
          log_OZONE10[0] = 0;
          log_OZONE10[1] = 0;
          log_OZONE10[2] = 0;
          Serial.printf("log_ozone:1:%d", log_ozone);
          eeprom_write();
          Serial.printf("log_ozone:2:%d", log_ozone);
          Serial.printf("log_OZONE10_0:%d", log_OZONE10[0]);
          Serial.printf("log_OZONE10_1:%d", log_OZONE10[1]);
          Serial.printf("log_OZONE10_2:%d", log_OZONE10[2]);
          md111.text = String(mkTimeString(log_OZONE10[0] / 10) + "    " + mkTimeString(log_OZONE10[1] / 10) + "    " + mkTimeString(log_OZONE10[2] / 10));
          labelText(md111);
          break;

      }
    }

    if ( 1 == encoder2Pushed ) {
      encoder2Pushed = 0;
      //    Serial.println("leave maintenanceselect1");
      return (2);
    }
    delay(100);

  }

}
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
void loop()
{
  static int powerstate = 0;
  static int pos1 = 0;
  static int pos2 = 0;

  Serial.println("mode=set enter");
  int kekka = set();
  Serial.println("mode=set exited");
  if ( 1 == kekka ) {
    Serial.println("mode=run enter");
    encoder1Pushed = 0;
    encoder2Pushed = 0;
    run();
    Serial.println("mode=run exited");
  }
  if ( 2 == kekka  && 1 == mode_X ) {
    setonstart();
  }


}

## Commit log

2021-01-16 change SSR SHARP S108T02
    [ESP32DUALDIAL-B_Cu.gbr, ESP32DUALDIAL-B_Mask.gbr, ESP32DUALDIAL-B_SilkS.gbr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]
2021-01-27 version 20210119
    [ESP32DUALDIAL-B_Cu.gbr, ESP32DUALDIAL-B_Mask.gbr, ESP32DUALDIAL-B_SilkS.gbr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]
2021-01-31 fix GPIO assign bug.
    [ESP32DUALDIAL-B_Cu.gbr, ESP32DUALDIAL-B_Mask.gbr, ESP32DUALDIAL-B_SilkS.gbr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]
2021-03-10 change to ROTARY ENCODER chattaling fix. and many change...
    [ESP32DUALDIAL-B_Cu.gbr, ESP32DUALDIAL-B_Mask.gbr, ESP32DUALDIAL-B_SilkS.gbr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]
2021-07-23 Ver.6 : Add test pads / NNC and SHARP SSR both support / mode jumper
    [ESP32DUALDIAL-B_Cu.gbr, ESP32DUALDIAL-B_Mask.gbr, ESP32DUALDIAL-B_SilkS.gbr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]
2021-10-26 Version6 release. Testpad add and follow more SSR type.
    [ESP32DUALDIAL-B_Cu.gbr, ESP32DUALDIAL-B_Mask.gbr, ESP32DUALDIAL-B_SilkS.gbr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]
2021-11-16 fix eeprom first use check
    [ESP32_DUALDIAL_OSS.ino]
2021-11-16 bug fix eeprom paramater 10 to 12
    [ESP32_DUALDIAL_OSS.ino]
2021-11-16 OZONE pin change to array from DEFINE
2023-04-15 modify Arduino sketch
2023-08-22 arduino schtch update
    [ESP32DUALDIAL.kicad_pcb, ESP32DUALDIAL.kicad_sch]
2023-10-12 V8 release
    [ESP32DUALDIAL-B_Cu.gbr, ESP32DUALDIAL-B_Mask.gbr, ESP32DUALDIAL-B_SilkS.gbr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]
2023-10-13 change to V8.1
    [ESP32DUALDIAL-B_Cu.gbr, ESP32DUALDIAL-B_Mask.gbr, ESP32DUALDIAL-B_Silkscreen.gbr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]
2025-07-16 change to V8.2
    [ESP32DUALDIAL-B_Cu.gbr, ESP32DUALDIAL-B_Mask.gbr, ESP32DUALDIAL-B_Silkscreen.gbr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]
